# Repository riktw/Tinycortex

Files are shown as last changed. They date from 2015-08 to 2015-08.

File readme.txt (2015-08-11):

A tiny MBED compatible board. 
In here are all the hardware design files and an GCC compatible blink a led.
Pinout and other helpfull files can be found here too. For more information have a look at the following blog posts:

http://justanotherelectronicsblog.com/?p=124
http://justanotherelectronicsblog.com/?p=139

Everything is cc-by-sa-3.0 licensed unless said otherwise

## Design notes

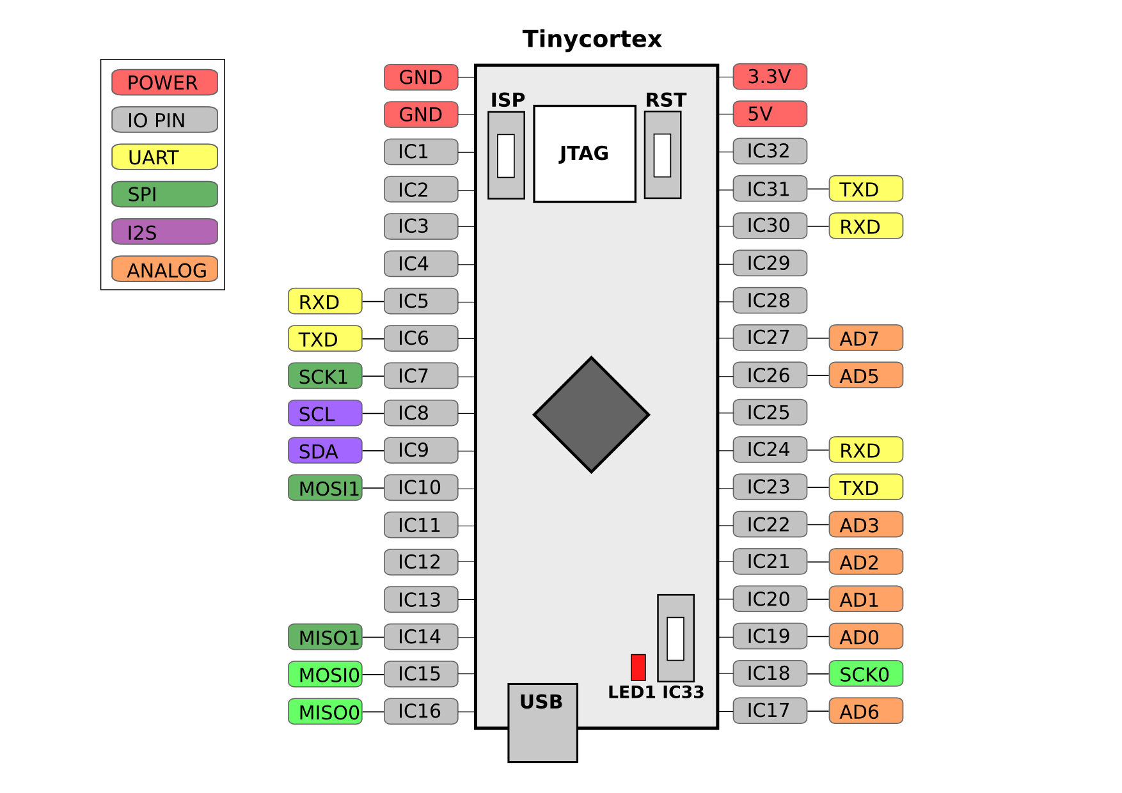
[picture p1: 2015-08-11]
pinout.png

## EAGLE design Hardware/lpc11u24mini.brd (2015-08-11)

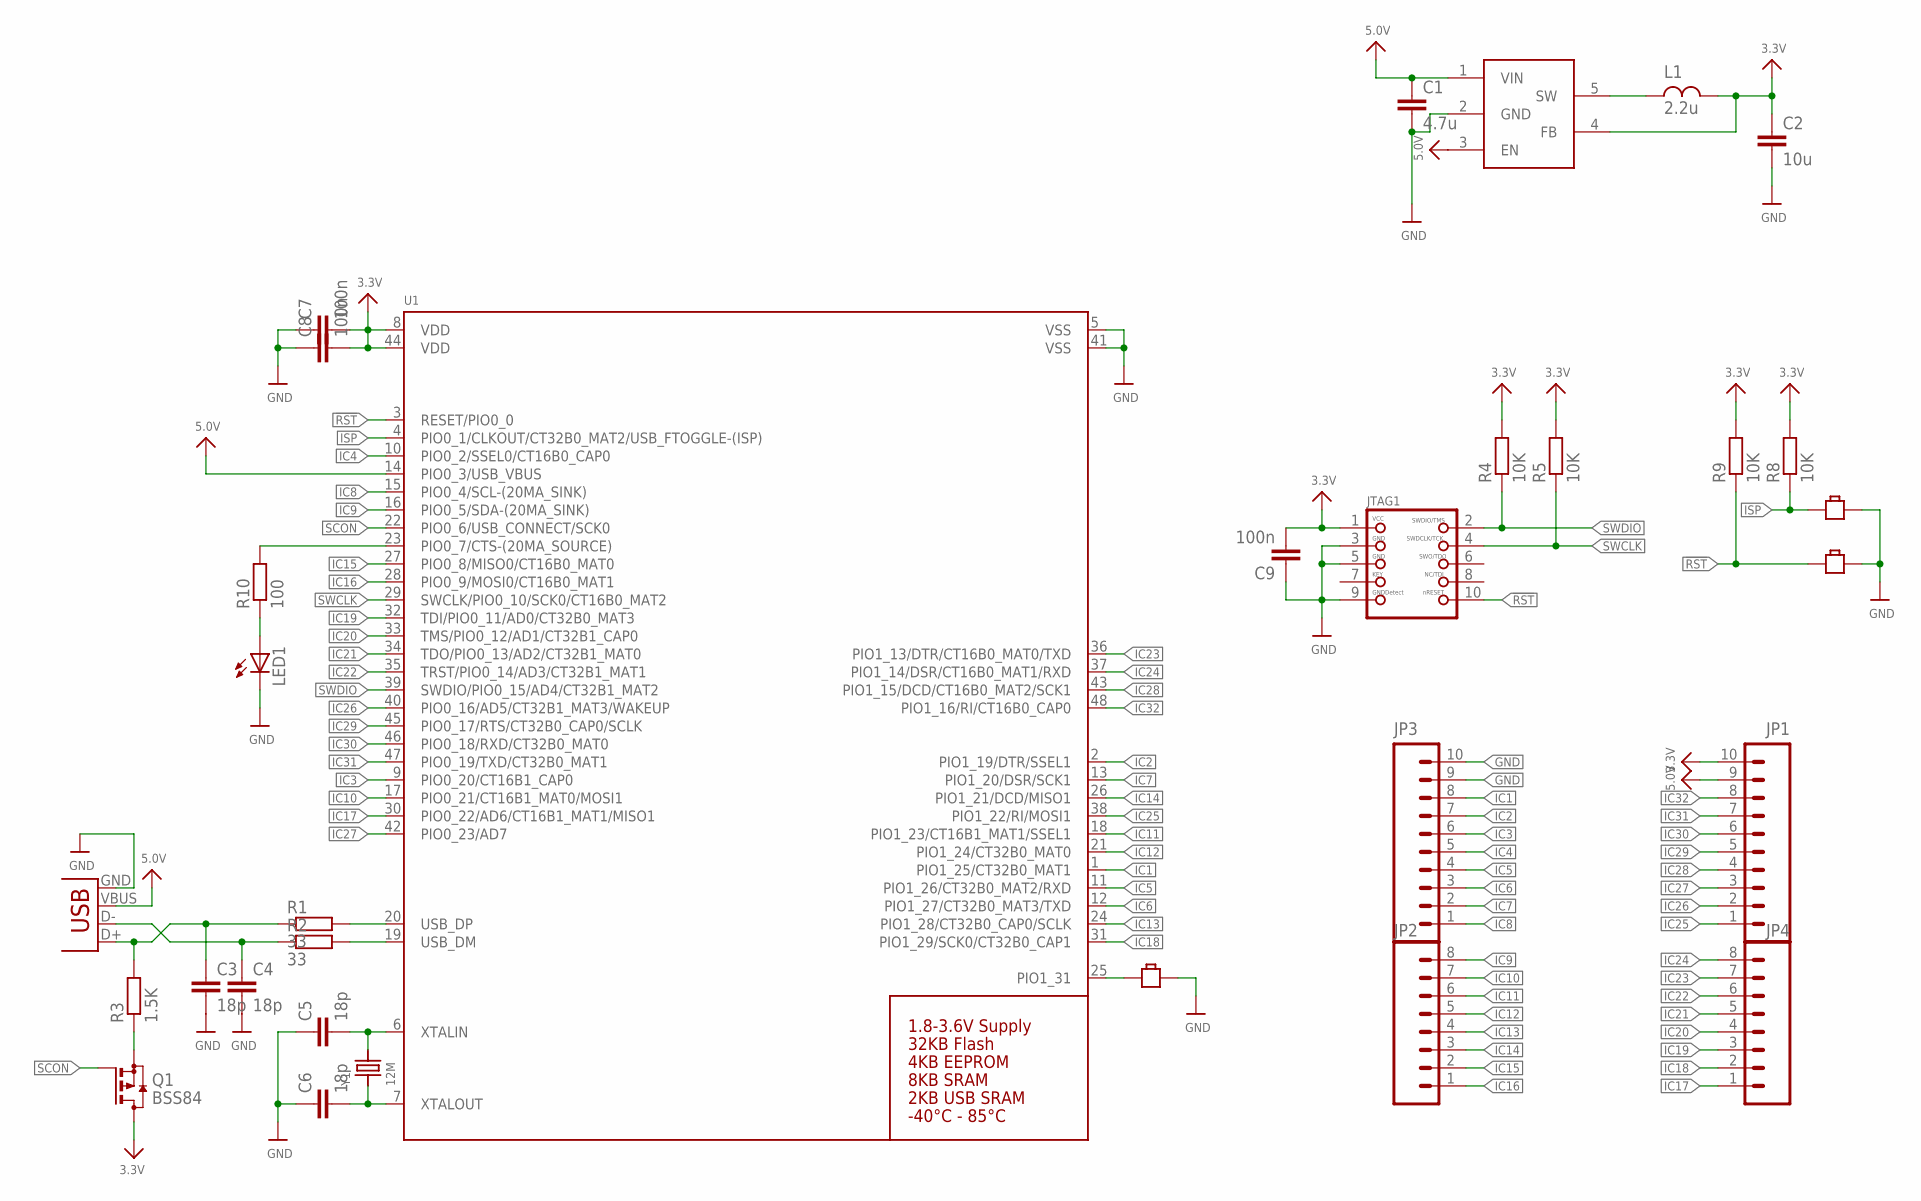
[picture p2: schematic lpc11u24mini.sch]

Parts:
B1, B2, B3: BUTTON-SMD-2P; BUTTON_2P_SMD
C1: 4.7u; C0603
C2: 10u; C0603
C3, C4, C5, C6: 18p; C0603
C7, C8, C9: 100n; C0603
JP1, JP3: M10SMD_MALE; 1X10_SMD_MALE
JP2, JP4: M08SMD-MALE; 1X08_SMD_MALE
JTAG1: JTAG-CORTEXM3; 2X05_1.27MM_SMT
L1: 2.2u; SRN2512
LED1: LEDSML0805; SML0805
Q1: BSS84; SOT23
R1, R2: 33; R0603
R3: 1.5K; R0603
R4, R5, R8, R9: 10K; R0603
R10: 100; R0603
U1: LPC11U24_QFP48; LQFP48
U$3: LM3671; SOT23-5
X1: USB-MICROB
Y1: 12M; CRYSTAL_3.2X2.5

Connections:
3.3V: C2.1, C7.2, C8.2, C9.2, JP1.10, JTAG1.1, L1.P$2 (2), Q1.3 (D), R4.2, R5.2, R8.2, R9.2, U1.8 (VDD), U1.44 (VDD), U$3.4 (FB)
5.0V: C1.1, JP1.9, U1.14 (PIO0_3/USB_VBUS), U$3.1 (VIN), U$3.3 (EN), X1.VBUS
!RST: B2.1, JTAG1.10, R9.1, U1.3 (RESET/PIO0_0)
DR_N: R2.2, U1.19 (USB_DM)
DR_P: R1.2, U1.20 (USB_DP)
D_N: C4.1, R2.1, X1.D-
D_P: C3.1, R1.1, R3.2, X1.D+
GND: B1.P$2, B2.P$2, B3.P$2, C1.2, C2.2, C3.2, C4.2, C5.1, C6.1, C7.1, C8.1, C9.1, JP3.9, JP3.10, JTAG1.3, JTAG1.5, JTAG1.9, LED1.C, U1.5 (VSS), U1.41 (VSS), U$3.2 (GND), X1.GND
IC1: JP3.8, U1.1 (PIO1_25/CT32B0_MAT1)
IC2: JP3.7, U1.2 (PIO1_19/DTR/SSEL1)
IC3: JP3.6, U1.9 (PIO0_20/CT16B1_CAP0)
IC4: JP3.5, U1.10 (PIO0_2/SSEL0/CT16B0_CAP0)
IC5: JP3.4, U1.11 (PIO1_26/CT32B0_MAT2/RXD)
IC6: JP3.3, U1.12 (PIO1_27/CT32B0_MAT3/TXD)
IC7: JP3.2, U1.13 (PIO1_20/DSR/SCK1)
IC8: JP3.1, U1.15 (PIO0_4/SCL-(20MA_SINK))
IC9: JP2.8, U1.16 (PIO0_5/SDA-(20MA_SINK))
IC10: JP2.7, U1.17 (PIO0_21/CT16B1_MAT0/MOSI1)
IC11: JP2.6, U1.18 (PIO1_23/CT16B1_MAT1/SSEL1)
IC12: JP2.5, U1.21 (PIO1_24/CT32B0_MAT0)
IC13: JP2.4, U1.24 (PIO1_28/CT32B0_CAP0/SCLK)
IC14: JP2.3, U1.26 (PIO1_21/DCD/MISO1)
IC15: JP2.2, U1.27 (PIO0_8/MISO0/CT16B0_MAT0)
IC16: JP2.1, U1.28 (PIO0_9/MOSI0/CT16B0_MAT1)
IC17: JP4.1, U1.30 (PIO0_22/AD6/CT16B1_MAT1/MISO1)
IC18: JP4.2, U1.31 (PIO1_29/SCK0/CT32B0_CAP1)
IC19: JP4.3, U1.32 (TDI/PIO0_11/AD0/CT32B0_MAT3)
IC20: JP4.4, U1.33 (TMS/PIO0_12/AD1/CT32B1_CAP0)
IC21: JP4.5, U1.34 (TDO/PIO0_13/AD2/CT32B1_MAT0)
IC22: JP4.6, U1.35 (TRST/PIO0_14/AD3/CT32B1_MAT1)
IC23: JP4.7, U1.36 (PIO1_13/DTR/CT16B0_MAT0/TXD)
IC24: JP4.8, U1.37 (PIO1_14/DSR/CT16B0_MAT1/RXD)
IC25: JP1.1, U1.38 (PIO1_22/RI/MOSI1)
IC26: JP1.2, U1.40 (PIO0_16/AD5/CT32B1_MAT3/WAKEUP)
IC27: JP1.3, U1.42 (PIO0_23/AD7)
IC28: JP1.4, U1.43 (PIO1_15/DCD/CT16B0_MAT2/SCK1)
IC29: JP1.5, U1.45 (PIO0_17/RTS/CT32B0_CAP0/SCLK)
IC30: JP1.6, U1.46 (PIO0_18/RXD/CT32B0_MAT0)
IC31: JP1.7, U1.47 (PIO0_19/TXD/CT32B0_MAT1)
IC32: JP1.8, U1.48 (PIO1_16/RI/CT16B0_CAP0)
ISP: B1.1, R8.1, U1.4 (PIO0_1/CLKOUT/CT32B0_MAT2/USB_FTOGGLE-(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)
LED: R10.2, U1.23 (PIO0_7/CTS-(20MA_SOURCE))
unnamed: B3.1, U1.25 (PIO1_31)
unnamed: L1.P$1 (1), U$3.5 (SW)
unnamed: Q1.2 (S), R3.1
unnamed: C6.2, U1.7 (XTALOUT), Y1.1
unnamed: C5.2, U1.6 (XTALIN), Y1.2
unnamed: LED1.A, R10.1
SCON: Q1.1 (G), U1.22 (PIO0_6/USB_CONNECT/SCK0)
SWCLK: JTAG1.4, R5.1, U1.29 (SWCLK/PIO0_10/SCK0/CT16B0_MAT2)
SWDIO: JTAG1.2, R4.1, U1.39 (SWDIO/PIO0_15/AD4/CT32B1_MAT2)

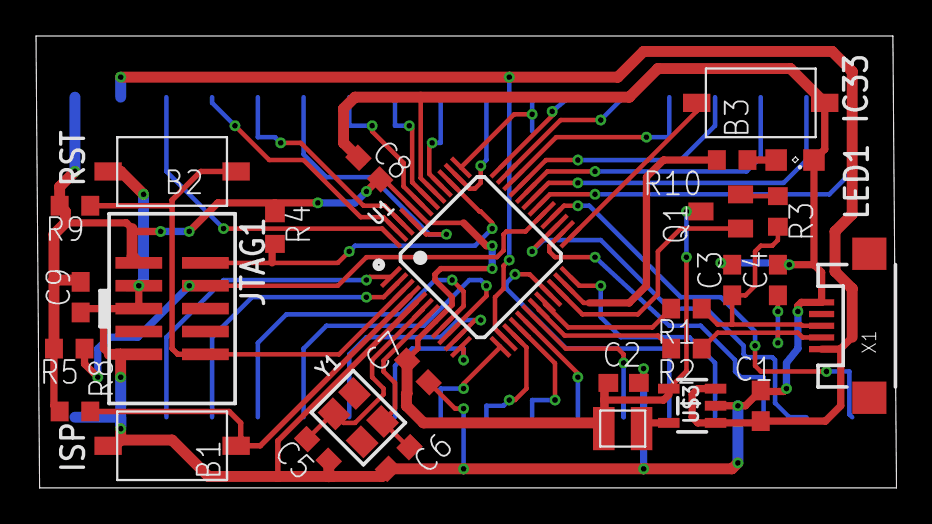
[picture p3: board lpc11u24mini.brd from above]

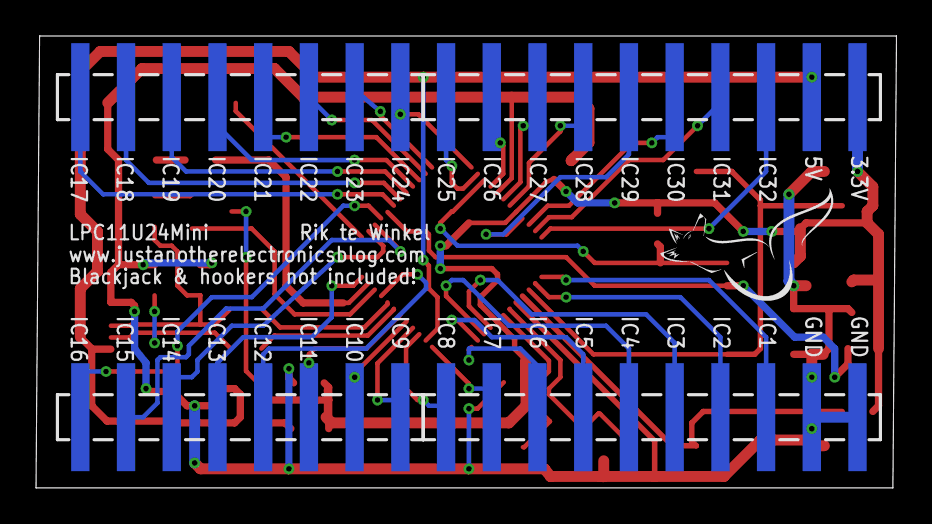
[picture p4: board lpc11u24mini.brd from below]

Board: 2 copper layers, 47.8 x 25.1 mm, 32 parts (4 on the bottom side), 51 nets.

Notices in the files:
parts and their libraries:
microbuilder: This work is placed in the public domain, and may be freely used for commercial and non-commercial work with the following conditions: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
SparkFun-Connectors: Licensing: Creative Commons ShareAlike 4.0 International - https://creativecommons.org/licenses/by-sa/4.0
